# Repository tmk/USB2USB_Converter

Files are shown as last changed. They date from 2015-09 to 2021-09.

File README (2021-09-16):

USB to USB keyboard converter
=============================
2021/09/16

Update
------
2015/02 Rev.A
2015/09 Rev.B   Fixed footprints, see TODO.txt.
2016/12 Rev.C   Fixed X'tal footprints and value of capacitors and resistor.
2019/06 Rev.D   Update footprint with rounded pads
2019/09 Rev.E   Change QFP44 footprint and solder mask parameters
2020/02 Rev.F   Change Xtal footprint and paste clearance
2020/12 Rev.G   Remove LED

Resourses
---------
MAX3421E datasheet:
http://datasheets.maximintegrated.com/en/ds/MAX3421E.pdf

MAX3421E kicad library:
https://github.com/dominicgs/BeagleDancer/blob/master/hardware/lib/beagledancer.lib

Circuit@HOME USB Host Shield
http://www.circuitsathome.com/products-page/arduino-shields/usb-host-shield-2-0-for-arduino

3.3V Teensy
https://www.pjrc.com/teensy/3volt.html

USB Host Shield 2.0
===================
Host Shield library:
    https://github.com/felis/USB_Host_Shield_2.0

Host Shield library debug output: USB_HOST_SERIAL
    https://github.com/felis/USB_Host_Shield_2.0/blob/master/settings.h

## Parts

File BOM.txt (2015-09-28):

BOM of USB to USB keyboard converter
====================================
2015/03/09

Ref     Value		Footprint
----------------------------------------------------
C1	1u		C_0603_HandSoldering
C10	18p		C_0603_HandSoldering
C11	18p		C_0603_HandSoldering
C12	1u		C_0603_HandSoldering
C13	1u		C_0603_HandSoldering
C2	1u		C_0603_HandSoldering
C3	0.1u		C_0603_HandSoldering
C4	18p		C_0603_HandSoldering
C5	18p		C_0603_HandSoldering
C6	0.1u		C_0603_HandSoldering
C7	0.1u		C_0603_HandSoldering
C8	4.7u		C_1206_HandSoldering
C9	0.1u		C_0603_HandSoldering
D1	LED		LED_2012_HSOL
J1	USB_B		USB_B
J2	USB_A		USB_A
R1	22		R_0603_HandSoldering
R2	22		R_0603_HandSoldering
R3	1K		R_0603_HandSoldering
R4	33		R_0603_HandSoldering
R5	33		R_0603_HandSoldering
R6	2K2(1K)		R_0603_HandSoldering
SW1	PUSH		SW_ALPS_SKRP
U1	ATMEGA32U4	LQFP-44_10x10mm_Pitch0.8mm
U2	MAX3421E	LQFP-32_5x5mm_Pitch0.5mm
U3	MIC5504-3.3	SC70-6_Handsoldering
X1	16MHz		crystal_FA238-TSX3225
X2	12MHz		crystal_FA238-TSX3225

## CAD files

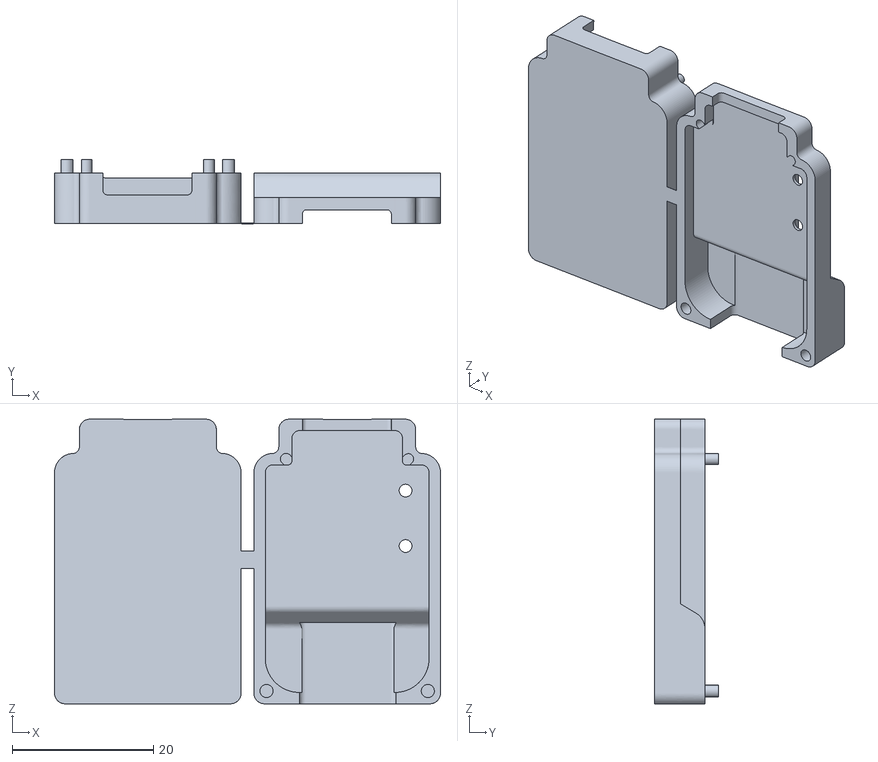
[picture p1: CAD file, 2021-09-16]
3D Printed Case/USB-USB_case.stl
54.6 x 9.06 x 40.3

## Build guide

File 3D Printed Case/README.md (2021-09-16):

# 3D Printed Case for TMK USB-USB converter

Created in Autodesk Fusion 360.

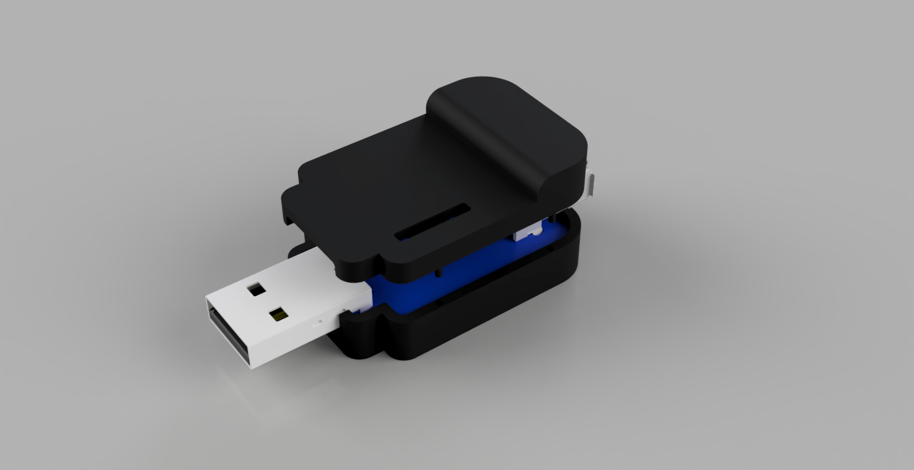
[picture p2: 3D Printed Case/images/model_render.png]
3D Case Render


### Notes for printing

There is a very small peice connecting the 2 halves of the shells together, this is so it is recognised as a single print.  It should be small enough enough that it is ignored, but if it is flagged by your print software or 3rd party printer you can tell them to disregard it.

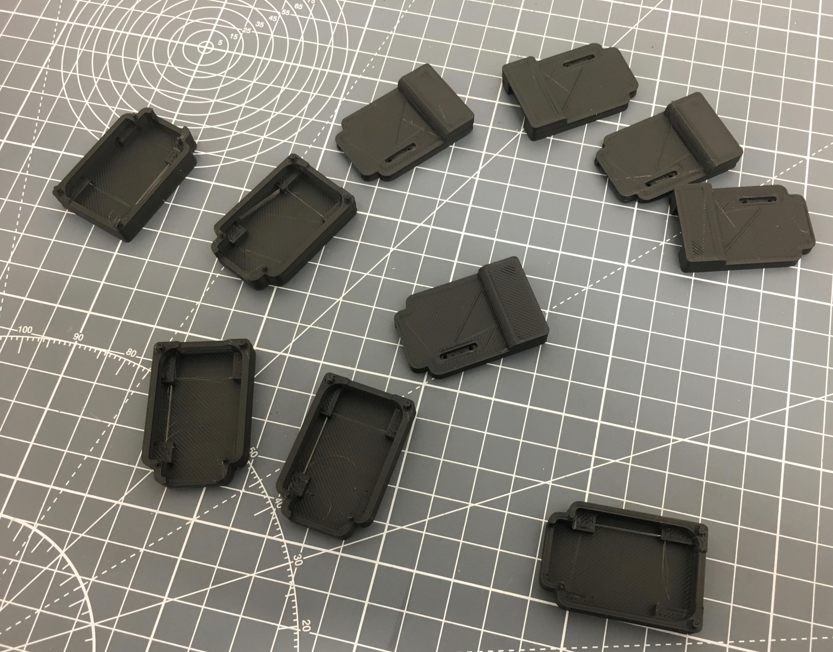
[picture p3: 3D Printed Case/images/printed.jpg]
Printed Cases


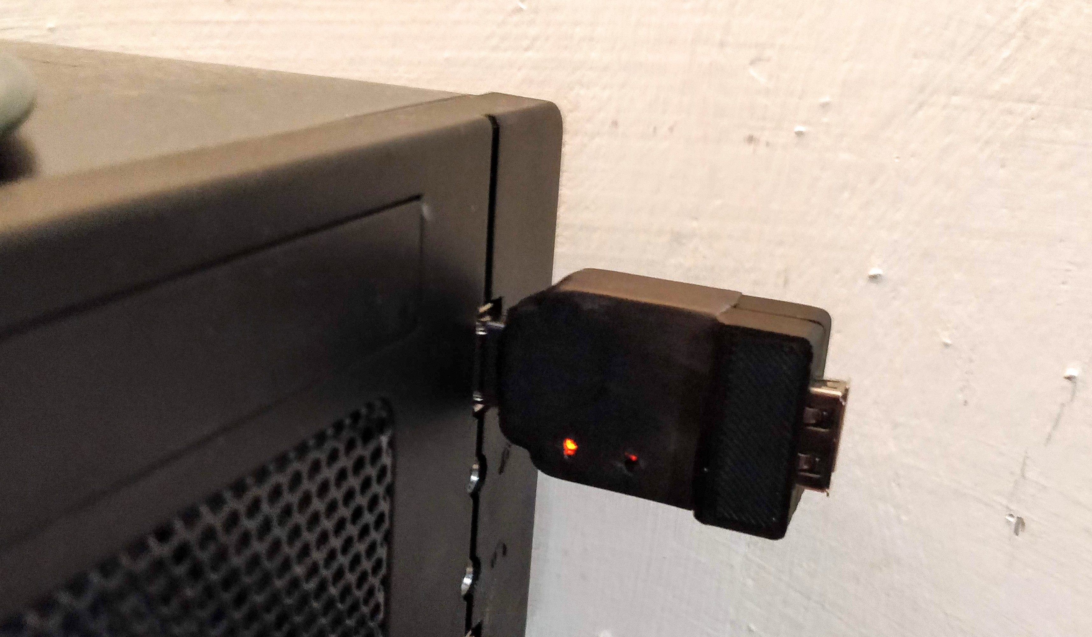
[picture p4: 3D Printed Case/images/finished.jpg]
In use


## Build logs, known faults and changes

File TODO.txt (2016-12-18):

TODO
====

Rev.A
-----
- 3.3V LDO regulator MIC5504 footprint is wrong size and should be 5 lands.
    DONE: 2015/09/28 changed footprint to SOT23-5_HSOL
- Both QFP footprint should has a clear 1pin mark.
    DONE: 2015/09/28
- Add pin markings on USB pads for cable soldering.
    DONE: 2015/09/28

Rev.B
-----
- X'tal foot print
- X'tal ground connection
- Capacitor value for X'tal: 18p -> 10p
- Resistor value: 2K2->1K
    ALL DONE: 2016/12/17

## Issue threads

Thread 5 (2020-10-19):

Please show the detail of Pro Micro connect with mini USB Host Shiled 2.0

PotatoJet, 2020-10-19:
@tmk I don't know how to connect them.
Could you please show a picture about connections?
Thanks！

PotatoJet, 2020-10-24:
I am better use U2U.
Pro Micro method is bad idea,because I bought a pro micro made in china,bootloader is Lilypad USB!!!
Damn it！So qmk toolbox can't recognize it！

Closed 2020-10-24.

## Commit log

2014-12-22 Add initial schematic
    [usb2usb.sch]
2014-12-23 Fix power pin of USB connector
    [usb2usb.sch]
2015-09-28 Fix Rev.A TODOs; improper footprints
    [usb2usb.kicad_pcb, usb2usb.sch]
2016-12-18 Fix xtal footprint and silk prints
    [usb2usb.kicad_pcb]
2018-10-26 Added 3D printed case files
    Added a directory including an stl file for a 3D printed case and
    details about it
    [USB-USB_case.stl]
2018-10-26 Revert "Added 3D printed case files"
    This reverts commit 85451b4d851be881b3f125b8ef953f02d10fc59e.
    [USB-USB_case.stl]
2018-10-26 Added 3D printed case files
    Created a directory including an stl file for a 3D printed case and
    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
    [USB-USB_case.stl]
2019-06-17 Update footprint with rounded pads
    [usb2usb.kicad_pcb, usb2usb.sch]
2019-09-06 Change QFP44 footprint and solder mask parameters
    [usb2usb.kicad_pcb]
2019-10-16 Minor change to Case and added collada file
    [USB-USB_case.stl]
2020-02-20 Change Xtal footprint and paste clearance
    [usb2usb.kicad_pcb]
2020-12-09 Remove LED
    [usb2usb.kicad_pcb, usb2usb.sch]
